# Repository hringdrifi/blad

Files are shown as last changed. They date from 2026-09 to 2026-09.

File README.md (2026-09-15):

<p align="center">
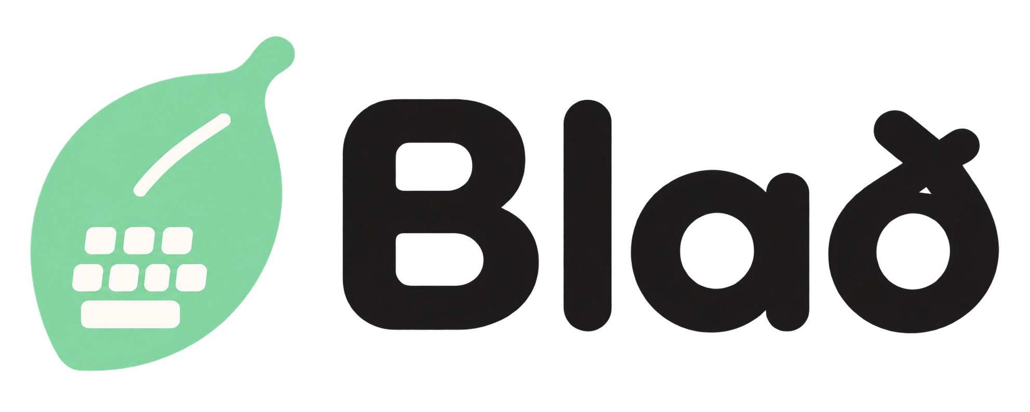
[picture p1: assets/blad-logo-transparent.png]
Blað
  
</p>

The previous HY0020-based version is available in the [blad-hy0020 repository](https://github.com/hringdrifi/blad-hy0020).

Blað is a compact wireless keyboard design project by [hringdrifi](https://github.com/hringdrifi).

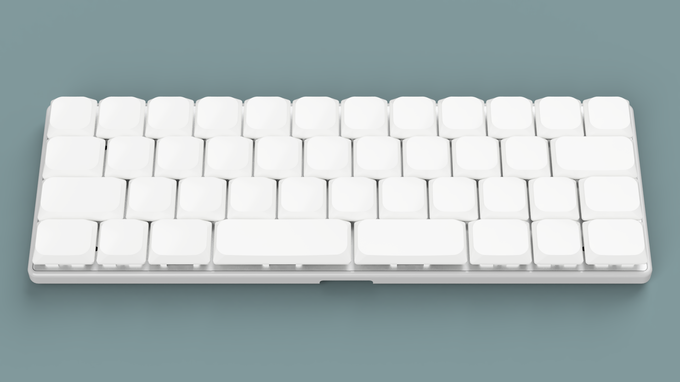
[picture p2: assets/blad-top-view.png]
Blað, top view


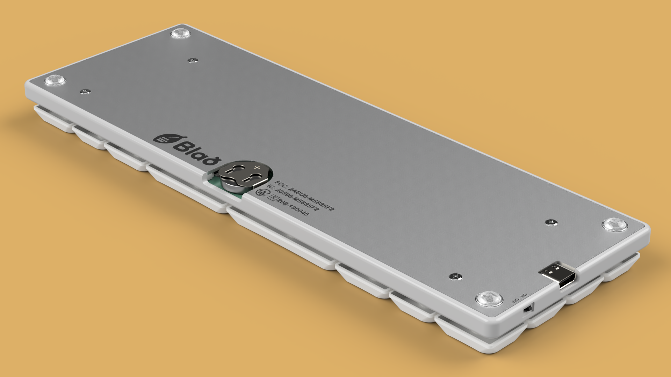
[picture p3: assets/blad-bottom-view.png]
Blað, bottom view


The design uses 42 Kailh Choc hot-swap switch positions and a [MinewSemi MS88SF21](https://en.minewsemi.com/bluetooth-module/nrf52840ms88sf21) wireless module. Development is currently targeting the MS88SF21 variant based on the Nordic nRF52840.

## Supported components

The design supports the following keyboard components:

- Kailh Choc V2 switches
- Kailh low-profile sockets
- [Chosfox Cross-Core Low-Profile Stabilizers](https://chosfox.com/products/chosfox-cross-core-satellite-switch-for-low-profile-keyboards)

All PCB components can be soldered by hand, so no reflow oven is required for assembly.

Confirm the exact part variants and mechanical fit before ordering or manufacturing.

## Connectivity and firmware

Blað is intended to support both Bluetooth Low Energy (BLE) and USB through the nRF52840-based MS88SF21. It uses a CR1632 lithium coin cell for battery operation. The nRF52840-based MS88SF21 module is TELEC-certified for use in Japan (Giteki compliant).

The MS88SF21 is also available with an nRF52833, but the first hardware and firmware revision in this repository will target the nRF52840 version. Compatibility between the two module variants and with the existing PCB design is still being evaluated; verify the module pinout, footprint, power supply, USB routing, and firmware target before manufacturing hardware.

## Project status

This repository is being migrated from the previous FDK HY0020/nRF52832 design to the MS88SF21/nRF52840. The current KiCad and case files may still contain HY0020-specific circuitry, footprints, markings, dimensions, or other assumptions and should not yet be treated as a completed MS88SF21 design.

Validate the module variant, PCB compatibility, USB implementation, switches, battery, firmware, manufacturing process, and assembly before building hardware.

## Available files

- [`pcb/`](pcb/) — KiCad source files for the keyboard PCB and plates
  - [`blad.kicad_pcb`](pcb/blad.kicad_pcb) — main keyboard PCB
  - [`blad.kicad_sch`](pcb/blad.kicad_sch) — schematic
  - [`blad_switch_plate.kicad_pcb`](pcb/blad_switch_plate.kicad_pcb) — switch plate PCB
  - [`blad_bottom_plate.kicad_pcb`](pcb/blad_bottom_plate.kicad_pcb) — bottom plate PCB
  - [`smidr.pretty/`](pcb/smidr.pretty/) — custom footprints referenced by the design
  - [`3dmodels/`](pcb/3dmodels/) — STEP models for selected components
- [`case/`](case/) — STEP models for the case assembly
  - [`blad_switch_plate.step`](case/blad_switch_plate.step) — case switch plate
  - [`blad_bumper.step`](case/blad_bumper.step) — bumper layer
- [`pcb/README.md`](pcb/README.md) — Smiðr KiCad-export details
- [`case/README.md`](case/README.md) — case-model notes and file roles

## License

The design data in `pcb/` and `case/` is licensed under the [CERN Open Hardware Licence Version 2 - Permissive (CERN-OHL-P-2.0)](LICENSE).

This license permits use, modification, manufacture, and sale of the design data and products made from it. Modified design data does not need to be published, but applicable notices must be retained and modifications must be documented. The design data and any resulting products are provided without warranty.

## Disclaimer

Verify dimensions, clearances, component compatibility, manufacturability, and safety for your own build before making any parts. Use of these files is at your own risk.

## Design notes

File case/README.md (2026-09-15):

# Blað case models

This directory contains the STEP models for the Blað case. The models are supplied as separate parts so they can be inspected, modified, or incorporated into a manufacturing workflow.

| File | Role |
| --- | --- |
| [`blad_switch_plate.step`](blad_switch_plate.step) | Switch plate for the case assembly. |
| [`blad_bumper.step`](blad_bumper.step) | Bumper layer between the plate and bottom plate. |

## Assembly hardware

- M2 standoffs, 4.5 mm long
- M2 screws, 3 mm long

## Use

Import both STEP files into the same CAD assembly and align them by their native coordinates. The models are design data rather than a production-ready manufacturing package: confirm dimensions, fit with the PCB and components, material selection, tolerances, and manufacturing constraints before fabrication.

The case models are licensed under the [CERN Open Hardware Licence Version 2 - Permissive (CERN-OHL-P-2.0)](../LICENSE).

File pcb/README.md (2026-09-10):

# Blað KiCad export

Generated by Smiðr.

This KiCad export places center-origin Smiðr switch footprints from the physical layout and emits a matching schematic with keyboard matrix nets.

- Plate PCB: blad_switch_plate.kicad_pcb contains center-origin key-hole footprints for the same physical layout.
- Switch footprint: Smidr:SW_Smidr_Choc_Hotswap
- Diode footprint: Smidr:D_Smidr_SOD123
- Footprint library: smidr.pretty is included in this ZIP and referenced by fp-lib-table.
- Switch outlines: keycap, fab, and courtyard geometry are generated from each key's w/h.
- RGB Matrix: no per-key RGB LEDs placed.
- Backlight: no per-key backlight LEDs placed.
- Direct-pin projects connect each switch between its direct GPIO net and GND.
- Matrix projects connect switches and diodes using ROWn/COLn nets.
- MS88SF21 symbol: `Smidr:MinewSemi_nRF52840_MS88SF21_5V_USB_Available` follows the MinewSemi Store product name `nRF52840-MS88SF21` and its `5V / USB Available` variant; the manufacturer hardware code `1Y40AI-U` is retained in the `Hardware Code` property.
- MS88SF21 footprint: `Smidr:RF_Module_MinewSemi_MS88SF21` uses the manufacturer's 1.8 x 0.8 mm recommended lands and includes the PCB-antenna keepout.
- MS88SF21 3D model: `smidr.3dshapes/MS88SF21.step` is generated locally from the manufacturer dimensions by `scripts/generate_ms88sf21_step.py`.
- The MS88SF21 library assets are available for migration, but the existing HY0020 circuit and board placement have not been replaced yet.
- Distributor order codes and module hardware codes are intentionally not used as the primary symbol name; record them as supplier-specific purchasing data when needed.

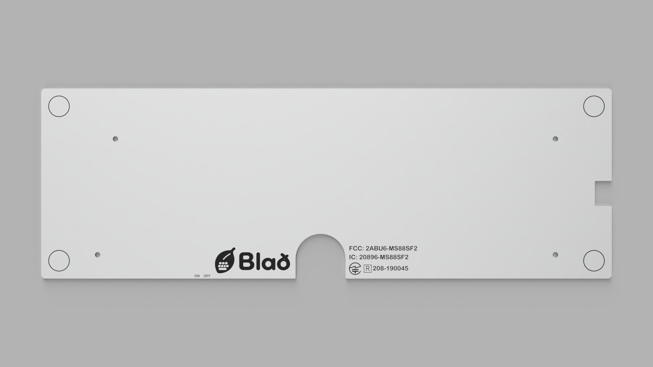
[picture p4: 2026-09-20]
case/barda_bottom_plate_2026-Sep-19_04-16-37PM-000_CustomizedView33586186082.png

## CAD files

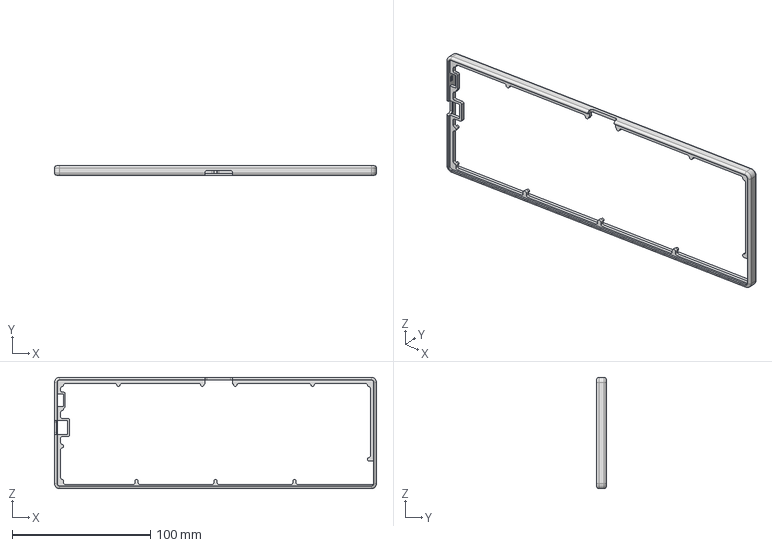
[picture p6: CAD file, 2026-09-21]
case/blad_bumper.step
233.0 x 6.90 x 80.6 mm

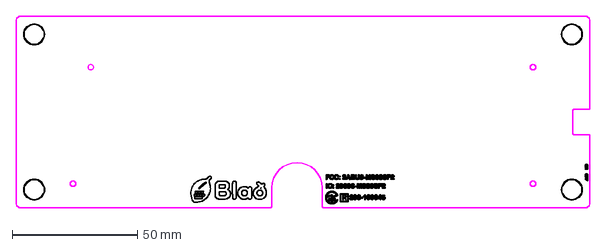
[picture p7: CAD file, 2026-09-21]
case/blad_bottom_plate_Silkscreen.dxf
228.6 x 76.2 mm

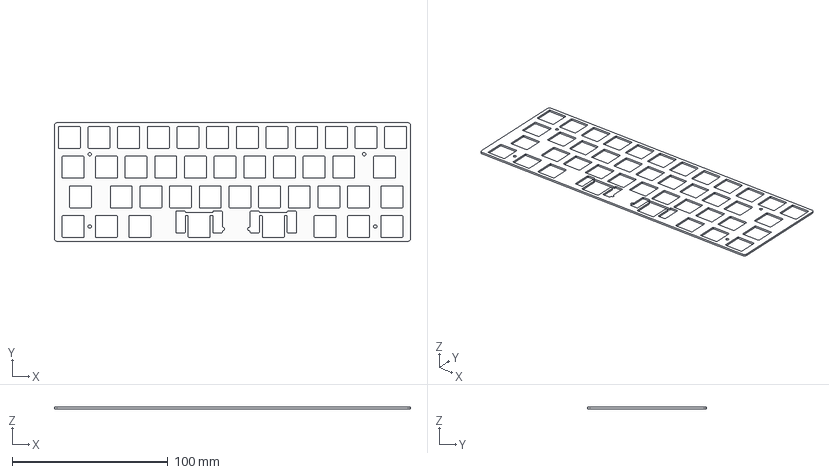
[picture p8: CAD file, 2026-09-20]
case/blad_switch_plate.step
228.6 x 76.2 x 1.20 mm

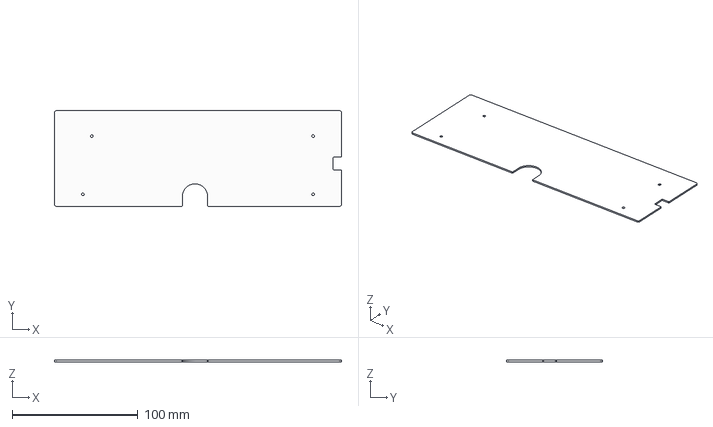
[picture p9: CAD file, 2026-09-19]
case/blad_bottom_plate.step
228.6 x 76.2 x 1.20 mm

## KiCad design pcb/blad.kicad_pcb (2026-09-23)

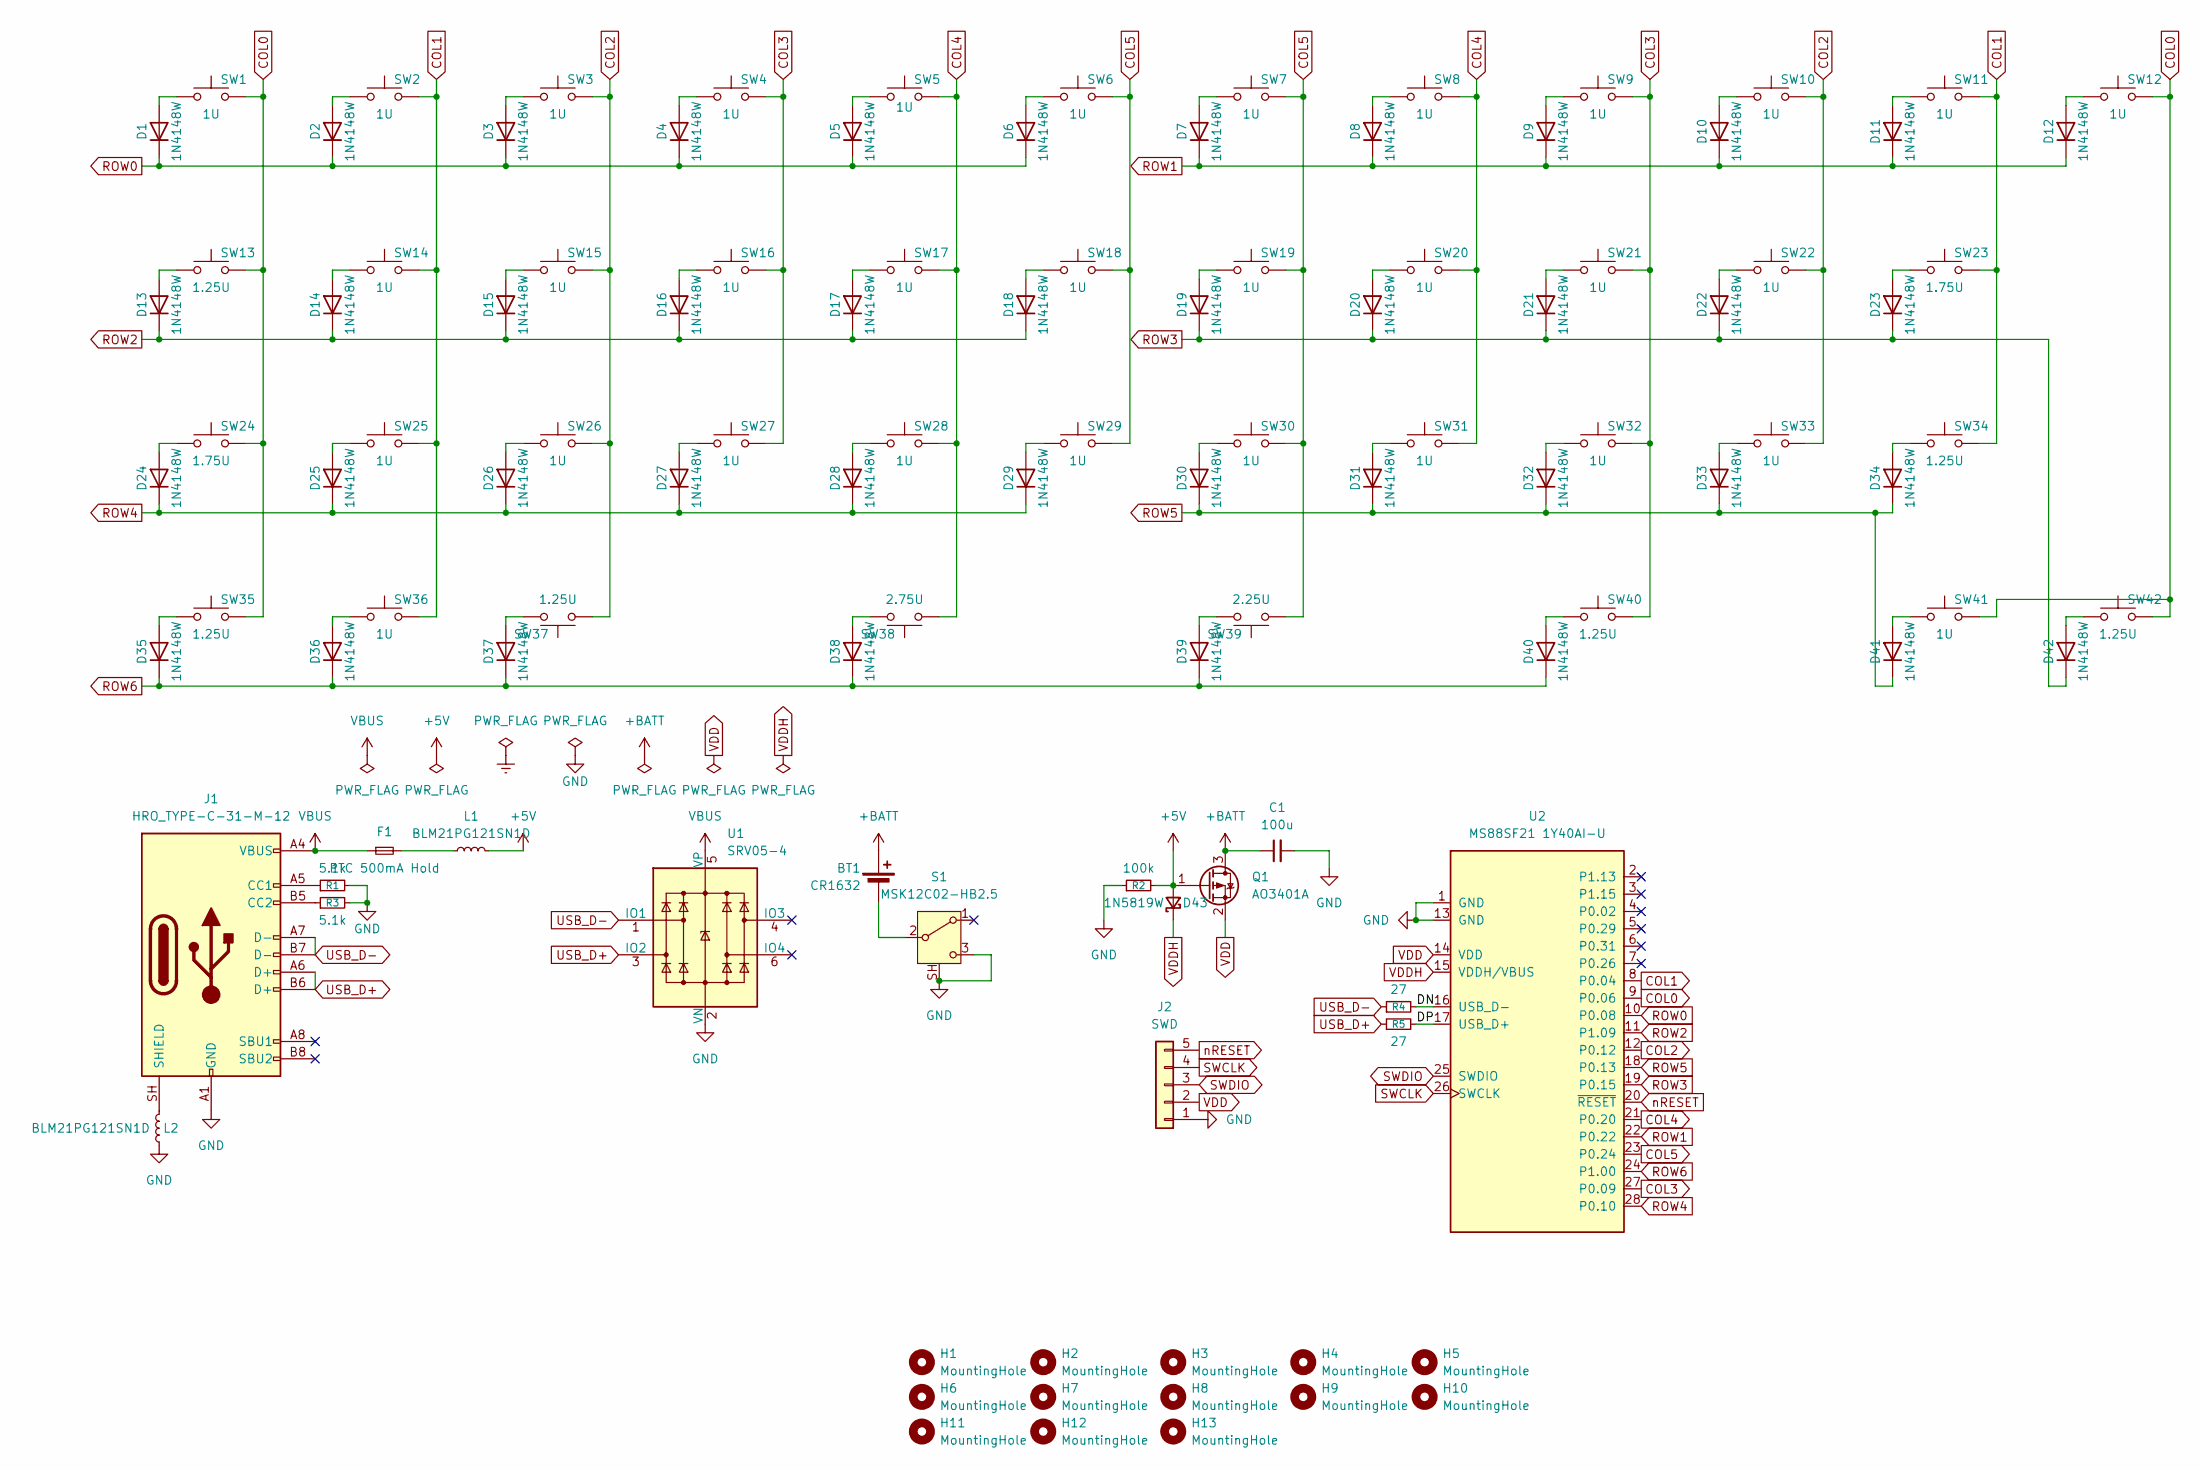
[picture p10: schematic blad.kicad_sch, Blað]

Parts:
BT1: CR1632; BatteryHolder_Takachi_BS-S-1632
C1: 100u; C_1206_3216Metric; JLCPCB Part # C15008
D1, D2, D3, D4, D5, D6, D7, D8, D9, D10, D11, D12, D13, D14, D15, D16, D17, D18, D19, D20, D21, D22, D23, D24, D25, D26, D27, D28, D29, D30, D31, D32, D33, D34, D35, D36, D37, D38, D39, D40, D41, D42: 1N4148W; D_SOD-123
D43: 1N5819W; D_SOD-123; JLCPCB Part # C2988774
F1: PTC 500mA Hold; Fuse_1206_3216Metric; JLCPCB Part # C151162
H1, H2, H3, H4, H5, H6, H7, H8, H9, H10, H11, H12, H13: MountingHole; MountingHole_2.1mm
J1: HRO_TYPE-C-31-M-12; USB_C_Receptacle_HRO_TYPE-C-31-M-12; JLCPCB Part # C165948
J2: SWD; PinHeader_1x05_P1.27mm_Vertical
L1, L2: BLM21PG121SN1D; L_0805_2012Metric; JLCPCB Part # C79382
Q1: AO3401A; SOT-23; JLCPCB Part # C15127
R1, R3: 5.1k; R_0603_1608Metric; JLCPCB Part # C23186
R2: 100k; R_0603_1608Metric; JLCPCB Part # C25803
R4, R5: 27; R_0603_1608Metric; JLCPCB Part # C25190
S1: MSK12C02-HB2.5; SW_SPDT_Shouhan_MSK12C02; JLCPCB Part # C47020937
SW1, SW2, SW3, SW4, SW5, SW6, SW7, SW8, SW9, SW10, SW11, SW12, SW14, SW15, SW16, SW17, SW18, SW19, SW20, SW21, SW22, SW25, SW26, SW27, SW28, SW29, SW30, SW31, SW32, SW33, SW36, SW41: 1U; SW_Smidr_Choc_Hotswap
SW13, SW34, SW35, SW37, SW40, SW42: 1.25U; SW_Smidr_Choc_Hotswap
SW23, SW24: 1.75U; SW_Smidr_Choc_Hotswap
SW38: 2.75U; SW_Smidr_Choc_Hotswap
SW39: 2.25U; SW_Smidr_Choc_Hotswap
U1: SRV05-4; SOT-23-6; JLCPCB Part # C7420376
U2: MS88SF21 1Y40AI-U; RF_Module_MinewSemi_MS88SF21; MPN 1Y40AI-U

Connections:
+5V: D43.2 (A), L1.2, Q1.1 (G), R2.2
+BATT: BT1.1 (+), C1.1, Q1.3 (D)
/DN: R4.2, U2.16 (USB_D-)
/DP: R5.2, U2.17 (USB_D+)
COL0: SW1.2, SW12.2, SW13.2, SW24.2, SW35.2, SW41.2, SW42.2, U2.9 (P0.06)
COL1: SW2.2, SW11.2, SW14.2, SW23.2, SW25.2, SW34.2, SW36.2, U2.8 (P0.04)
COL2: SW3.2, SW10.2, SW15.2, SW22.2, SW26.2, SW33.2, SW37.1, U2.12 (P0.12)
COL3: SW4.2, SW9.2, SW16.2, SW21.2, SW27.2, SW32.2, SW40.2, U2.27 (P0.09)
COL4: SW5.2, SW8.2, SW17.2, SW20.2, SW28.2, SW31.2, SW38.1, U2.21 (P0.20)
COL5: SW6.2, SW7.2, SW18.2, SW19.2, SW29.2, SW30.2, SW39.1, U2.23 (P0.24)
GND: C1.2, J1.A1 (GND), J1.A12 (GND), J1.B1 (GND), J1.B12 (GND), J2.1, L2.1, R1.2, R2.1, R3.2, S1.3 (C), S1.SH, U1.2 (VN), U2.1 (GND), U2.13 (GND)
unnamed: BT1.2 (-), S1.2 (B)
unnamed: D1.2 (A), SW1.1
unnamed: D2.2 (A), SW2.1
unnamed: D3.2 (A), SW3.1
unnamed: D4.2 (A), SW4.1
unnamed: D5.2 (A), SW5.1
unnamed: D6.2 (A), SW6.1
unnamed: D7.2 (A), SW7.1
unnamed: D8.2 (A), SW8.1
unnamed: D9.2 (A), SW9.1
unnamed: D10.2 (A), SW10.1
unnamed: D11.2 (A), SW11.1
unnamed: D12.2 (A), SW12.1
unnamed: D13.2 (A), SW13.1
unnamed: D14.2 (A), SW14.1
unnamed: D15.2 (A), SW15.1
unnamed: D16.2 (A), SW16.1
unnamed: D17.2 (A), SW17.1
unnamed: D18.2 (A), SW18.1
unnamed: D19.2 (A), SW19.1
unnamed: D20.2 (A), SW20.1
unnamed: D21.2 (A), SW21.1
unnamed: D22.2 (A), SW22.1
unnamed: D23.2 (A), SW23.1
unnamed: D24.2 (A), SW24.1
unnamed: D25.2 (A), SW25.1
unnamed: D26.2 (A), SW26.1
unnamed: D27.2 (A), SW27.1
unnamed: D28.2 (A), SW28.1
unnamed: D29.2 (A), SW29.1
unnamed: D30.2 (A), SW30.1
unnamed: D31.2 (A), SW31.1
unnamed: D32.2 (A), SW32.1
unnamed: D33.2 (A), SW33.1
unnamed: D34.2 (A), SW34.1
unnamed: D35.2 (A), SW35.1
unnamed: D36.2 (A), SW36.1
unnamed: D37.2 (A), SW37.2
unnamed: D38.2 (A), SW38.2
unnamed: D39.2 (A), SW39.2
unnamed: D40.2 (A), SW40.1
unnamed: D41.2 (A), SW41.1
unnamed: D42.2 (A), SW42.1
unnamed: F1.2, L1.1
unnamed: J1.A5 (CC1), R1.1
unnamed: J1.B5 (CC2), R3.1
unnamed: J1.SH (SHIELD), L2.2
ROW0: D1.1 (K), D2.1 (K), D3.1 (K), D4.1 (K), D5.1 (K), D6.1 (K), U2.10 (P0.08)
ROW1: D7.1 (K), D8.1 (K), D9.1 (K), D10.1 (K), D11.1 (K), D12.1 (K), U2.22 (P0.22)
ROW2: D13.1 (K), D14.1 (K), D15.1 (K), D16.1 (K), D17.1 (K), D18.1 (K), U2.11 (P1.09)
ROW3: D19.1 (K), D20.1 (K), D21.1 (K), D22.1 (K), D23.1 (K), D42.1 (K), U2.19 (P0.15)
ROW4: D24.1 (K), D25.1 (K), D26.1 (K), D27.1 (K), D28.1 (K), D29.1 (K), U2.28 (P0.10)
ROW5: D30.1 (K), D31.1 (K), D32.1 (K), D33.1 (K), D34.1 (K), D41.1 (K), U2.18 (P0.13)
ROW6: D35.1 (K), D36.1 (K), D37.1 (K), D38.1 (K), D39.1 (K), D40.1 (K), U2.24 (P1.00)
SWCLK: J2.4, U2.26 (SWCLK)
SWDIO: J2.3, U2.25 (SWDIO)
USB_D+: J1.A6 (D+), J1.B6 (D+), R5.1, U1.3 (IO2)
USB_D-: J1.A7 (D-), J1.B7 (D-), R4.1, U1.1 (IO1)
VBUS: F1.1, J1.A4 (VBUS), J1.A9 (VBUS), J1.B4 (VBUS), J1.B9 (VBUS), U1.5 (VP)
VDD: J2.2, Q1.2 (S), U2.14 (VDD)
VDDH: D43.1 (K), U2.15 (VDDH/VBUS)
nRESET: J2.5, U2.20 (~RESET)

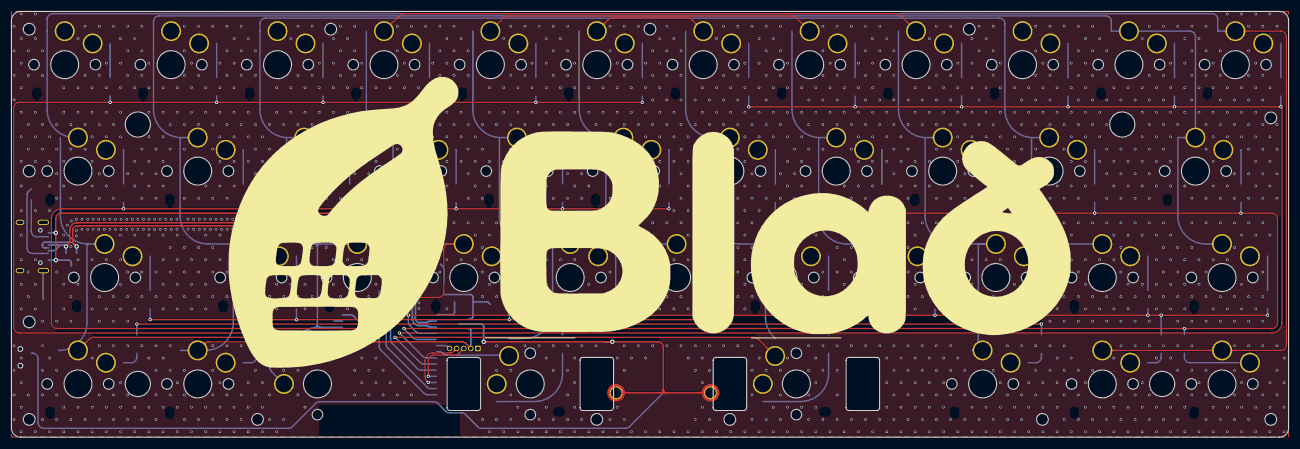
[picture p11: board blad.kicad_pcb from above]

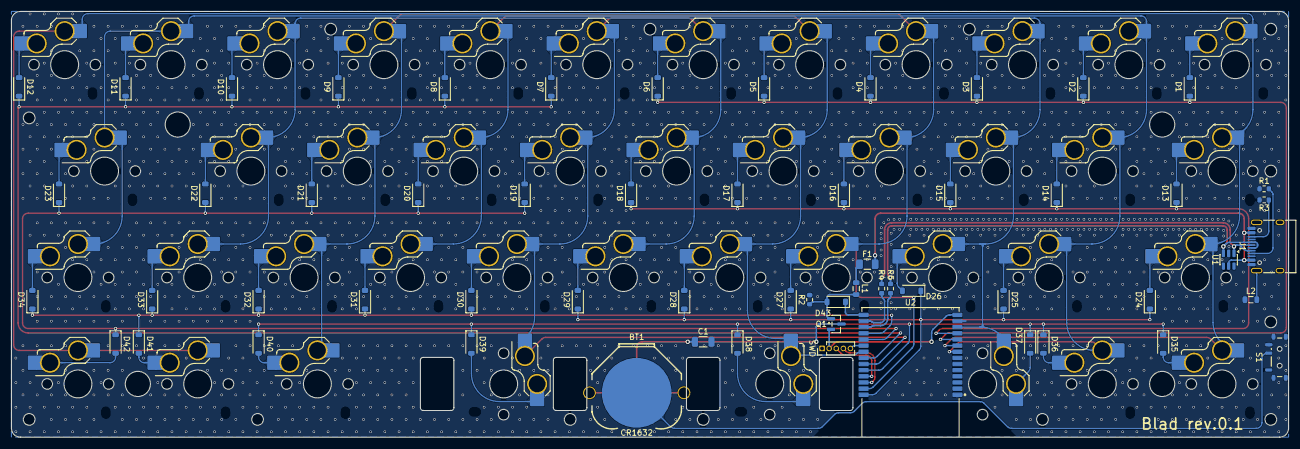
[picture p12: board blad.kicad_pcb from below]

Board: 2 copper layers, 228.6 x 76.2 mm, 114 parts (101 on the bottom side), 73 nets.

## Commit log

2026-09-08 Initial commit for MS88SF21 migration
    [blad.kicad_pcb, blad.kicad_sch, blad_battery_cap.step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]
2026-09-10 Migrate PCB to MS88SF21 module
    [blad.kicad_pcb, blad.kicad_sch]
2026-09-10 Update PCB power wiring and stabilizer cutouts
    [blad.kicad_pcb, blad.kicad_sch]
2026-09-10 Add logo footprint to PCB
    [blad.kicad_pcb]
2026-09-11 Fix USB grounding and add battery bulk capacitor
    [blad.kicad_pcb, blad.kicad_sch]
2026-09-11 Update PCB and plate designs
    [blad.kicad_pcb, blad_bottom_plate.kicad_pcb, blad_bottom_plate.kicad_sch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]
2026-09-11 Update bottom plate thickness and layout
    [blad_bottom_plate.kicad_pcb]
2026-09-11 Update USB-C model and plate geometry
    [blad.kicad_pcb, blad_switch_plate.kicad_pcb]
2026-09-11 Update bottom plate cutouts and PCB zones
    [blad.kicad_pcb, blad_bottom_plate.kicad_pcb, blad_bottom_plate.step]
2026-09-14 Add mounting holes and update case geometry
    [blad.kicad_pcb, blad.kicad_sch, blad_bottom_plate-B_Silkscreen.dxf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]
2026-09-15 Refactor application implementation
    [blad.kicad_pcb, blad_battery_cap.step]
2026-09-15 Document certification and hand-soldering
2026-09-16 Update PCB routing and schematic connectivity
    [blad.kicad_pcb, blad.kicad_sch]
2026-09-17 Update PCB design and bottom plate silkscreen
    [blad.kicad_pcb, blad_bottom_plate-B_Silkscreen.dxf, blad_bottom_plate.kicad_pcb]
2026-09-19 Update hardware design and bottom view render
    [blad.kicad_pcb, blad.kicad_sch, blad_bottom_plate-B_Silkscreen.dxf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]
2026-09-20 Update PCB and case design
    [blad.kicad_pcb, blad_bottom_plate_Silkscreen.dxf, blad_bumper.step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]
2026-09-20 Update SWD header to 1.27 mm pitch
    [blad.kicad_pcb, blad.kicad_sch]
2026-09-20 Update PCB layout and pad defaults
    [blad.kicad_pcb]
2026-09-20 Update diode values and PCB data
    [blad.kicad_pcb, blad.kicad_sch]
2026-09-21 Update keyboard design and renderings
    [blad.kicad_pcb, blad.kicad_sch, blad_bottom_plate.kicad_pcb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]
2026-09-21 Clean embedded font metadata
    [blad.kicad_pcb]
2026-09-21 Add bottom plate silkscreen backup
2026-09-21 Update PCB font metadata
    [blad.kicad_pcb]
2026-09-23 Update PCB copper zones
    [blad.kicad_pcb]
